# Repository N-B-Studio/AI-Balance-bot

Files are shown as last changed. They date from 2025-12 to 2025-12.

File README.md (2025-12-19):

# FOC-STM32-Balance-bot
FOC balance bot based on odrive-mini, STM32 and Linux PC
### Build video: https://youtu.be/XxXtfrMc1Zo
cover

## Project Overview
This project implements a self-balancing robot with AI capabilities, combining embedded STM32H7 firmware with Linux-based control scripts and face detection capabilities.

## Directory Structure & File Functions

### `/linux/` - Linux PC Control Scripts
Control scripts for the Raspberry Pi that interface with the STM32 microcontroller:

- **`h725_rc_joystick.py`** - Basic gamepad control script
  - Reads gamepad input from `/dev/input/event2`
  - Maps joystick axes to RC control values (-100 to 100)
  - Sends UART frames to STM32H725 via `/dev/serial0` (115200 baud)
  - Frame format: `0xAA 0x55 [FB] [LR] [checksum]` for forward/back and left/right control

- **`h725_rc_joystick_face.py`** - Gamepad control with face detection integration
  - Extends `h725_rc_joystick.py` with camera-based face detection
  - Uses Picamera2 to capture video frames (640x480)
  - Integrates with `face_detect.py` to detect faces using Haar Cascade classifier
  - Enables face-yaw mode when TL button is held (controls yaw based on face position)
  - Combines gamepad input with AI-based visual feedback

- **`face_detect.py`** - Face detection module
  - Uses OpenCV Haar Cascade classifier for real-time face detection
  - Captures frames from Raspberry Pi camera via Picamera2
  - Rotates frames 90° counterclockwise for proper orientation
  - Detects faces with configurable parameters (scaleFactor=1.3, minNeighbors=5, minSize=60x60)
  - Outputs detected face count and coordinates

- **`read_gamepad.py`** - Simple gamepad input reader
  - Basic utility to test gamepad connectivity
  - Reads raw controller events and displays them to console
  - Useful for debugging input device configuration

- **`read_elrs_crsf.py`** - ELRS/CRSF protocol decoder
  - Decodes ELRS (ExpressLRS) RC control signals via CRSF protocol
  - Runs at 420000 baud on `/dev/serial0`
  - Decodes RC_CHANNELS_PACKED frames (16 channels, 11-bit resolution: 0-2047)
  - Provides alternative to gamepad input using RC transmitter

- **`take_photo.py`** - Camera utility script
  - Captures still images from Raspberry Pi camera (640x480 resolution)
  - Saves photos in raw format and rotated versions (90° CW/CCW)
  - Useful for camera calibration and testing

### `/STM32/` - STM32H723 Embedded Firmware
Main firmware for the balance control MCU:

- **`Core/Inc/`** - Header files
  - `main.h` - Main program definitions
  - `BMI088*.h` - 6-axis IMU (accelerometer + gyroscope) driver headers
  - `bsp_fdcan.h`, `fdcan.h` - FDCAN/CAN communication interface
  - `usart.h`, `spi.h`, `dma.h` - Peripheral communication drivers
  - `gpio.h`, `tim.h` - GPIO and timer configurations

- **`Core/Src/`** - Source implementation files
  - `main.c` - Main control loop
  - `BMI088driver.c` - Low-level IMU register read/write
  - `BMI088Middleware.c` - High-level IMU data processing
  - `bsp_fdcan.c` - CAN bus initialization and handling
  - `usart.c`, `spi.c` - Serial and SPI communication
  - Other support files for system initialization

- **`Drivers/`** - STM32 HAL libraries and CMSIS
  - Hardware Abstraction Layer (HAL) for STM32H7xx
  - CMSIS (Cortex Microcontroller Software Interface Standard) headers

### `/3D-Model/` - CAD Files
3D CAD models for the robot mechanical structure and parts

### `/LICENSE` and `/README.md`
Project licensing information and this documentation file

## Hardware Components
- **MCU**: STM32H723 (ARM Cortex-M7)
- **IMU**: BMI088 (6-axis: 3-axis accelerometer + 3-axis gyroscope)
- **Motor Driver**: ODrive Mini (FOC - Field Oriented Control)
- **Controller**: Raspberry Pi or similar Linux board
- **Camera**: Raspberry Pi Camera Module 2
- **Communication**: UART (serial) for command interface, FDCAN for advanced control

## Communication Protocol
The main control protocol between Linux and STM32 is:
```
Frame: [0xAA] [0x55] [Forward/Back] [Left/Right] [Checksum]
- Forward/Back: -100 to 100 (signed 8-bit)
- Left/Right: -100 to 100 (signed 8-bit)
- Checksum: Sum of all bytes modulo 256
Baud Rate: 115200
```

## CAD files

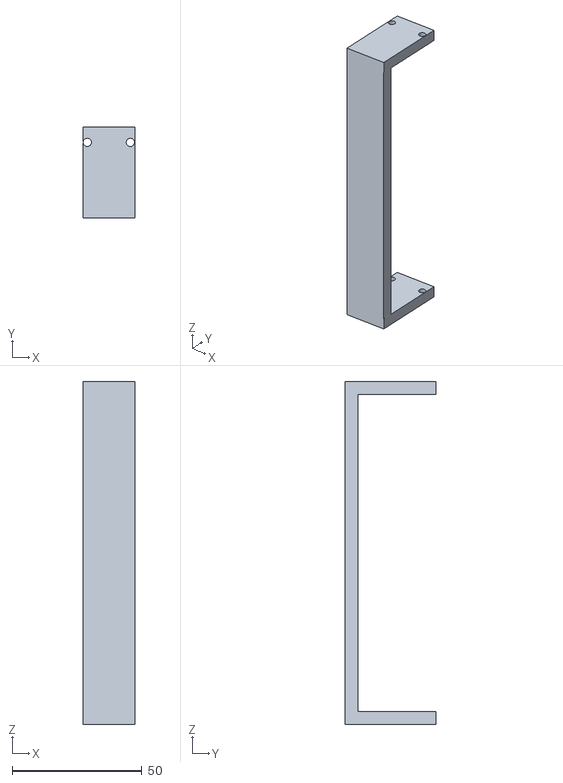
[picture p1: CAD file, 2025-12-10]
3D-Model/top.stl
20.0 x 35.0 x 132.0

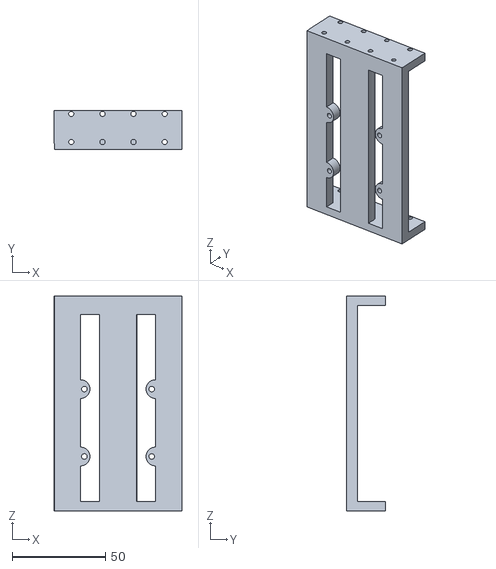
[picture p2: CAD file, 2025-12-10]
3D-Model/base.stl
68.3 x 21.0 x 115.0

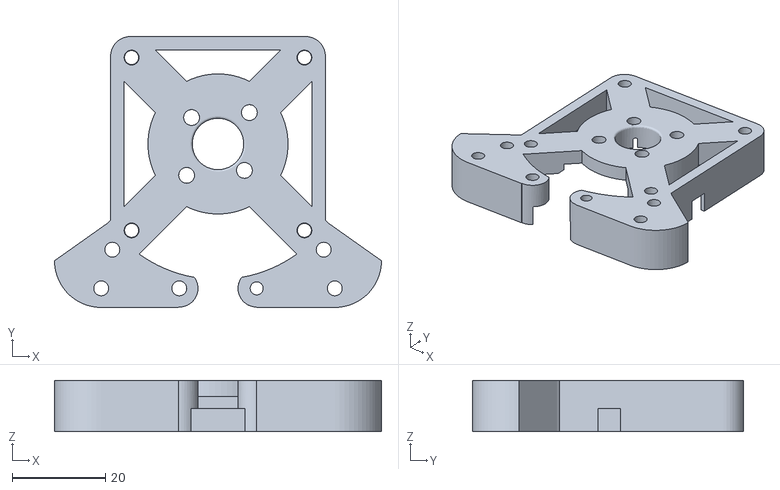
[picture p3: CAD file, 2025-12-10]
3D-Model/motor-base.stl
70.0 x 58.0 x 11.0

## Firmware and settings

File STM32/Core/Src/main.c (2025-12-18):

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
/* Includes ------------------------------------------------------------------*/
#include "main.h"
#include "dma.h"
#include "fdcan.h"
#include "spi.h"
#include "tim.h"
#include "usart.h"
#include "gpio.h"

/* USER CODE BEGIN Includes */
//#include "BMI088driver.h"
#include "BMI088Middleware.h"
#include <string.h>
#include <stdio.h>
/* USER CODE END Includes */


/* USER CODE BEGIN PV */
// --- Speed control loop configuration ---
    float v_target = 0.0f;          // Target linear velocity (can be 0 initially; later from RC/manual)
    float Kv_p     = 0.1f;          // Velocity P gain (tune gradually)
    float Kv_i     = 0.01f;         // Velocity I gain (start small)

    float v_integral      = 0.0f;
    float v_integral_limit = 5.0f;  // Prevent integral windup

    float base_pitch       = -1.5f; // Calibrated base pitch (degrees)
    float pitch_speed_limit = 6.0f; // Maximum pitch offset from joystick (degrees)
    float torque_limit      = 1.5f; // Max motor torque headroom


    // Velocity loop frequency: 1kHz / 10 = 100 Hz
	#define VEL_LOOP_DIV 10
	uint8_t vel_loop_counter = 0;

	volatile float odrive_left_vel  = 0.0f;
	volatile float odrive_right_vel = 0.0f;
	volatile float odrive_left_pos  = 0.0f;
	volatile float odrive_right_pos = 0.0f;

    // ===== YAW control =====
    float yaw               = 0.0f;      // Current yaw angle (approx. from integration)
    float Ky_p              = 0.0f;      // Yaw angle P gain
    float Ky_d              = 0.02f;     // Yaw rate D gain
    float yaw_torque_limit  = 0.4f;      // Maximum torque allocated to yaw

    // Wheel / robot geometry parameters (adjust to your robot)
    #define WHEEL_RADIUS_M   0.06f   // 0.06 m (example: 6 cm radius)
    #define GEAR_RATIO       1.0f    // Use 1.0 for direct drive, or set gearbox reduction ratio

    // Position loop
    float x_target      = 0.0f;     // Desired robot position (x=0)
    float Kx_p          = 0.0f;     // Position P gain (try 0.5~2 to start)
    float Kx_i          = 0.0f;     // Position I (start disabled; enable after tuning)
    float x_integral    = 0.0f;
    float x_int_limit   = 0.5f;     // Integral limit (meters)

    // Record initial average position at power-up
    float x0_turns = 0.0f;          // Origin in wheel turns
    uint8_t pos_initialized = 0;    // Position initialization flag

    // Global variables:
	volatile float odrive_left_pos_turns  = 0.0f;
	volatile float odrive_right_pos_turns = 0.0f;
	volatile float odrive_left_vel_turns  = 0.0f;
	volatile float odrive_right_vel_turns = 0.0f;

	// === RC command from Pi (forward/back & left/right) ===
	volatile float rc_fb = 0.0f;   // -1.0 .. +1.0 (forward/back)
	volatile float rc_lr = 0.0f;   // -1.0 .. +1.0 (left/right turn)

	static uint8_t uart10_rx_byte = 0;

	// UART10 simple frame parser state
	typedef enum {
	    RC_STATE_WAIT_AA = 0,
	    RC_STATE_WAIT_55,
	    RC_STATE_FB,
	    RC_STATE_LR,
	    RC_STATE_CHK
	} RC_State_t;

	static RC_State_t rc_state = RC_STATE_WAIT_AA;
	static int8_t rc_fb_int = 0;
	static int8_t rc_lr_int = 0;
	static uint8_t rc_checksum = 0;
	static uint8_t rc_sum = 0;
	// debug:
	volatile uint32_t rc_byte_count      = 0;   // total bytes seen on USART1
	volatile uint32_t rc_frame_ok_count  = 0;   // frames with correct checksum
	volatile int8_t   rc_last_fb_int     = 0;
	volatile int8_t   rc_last_lr_int     = 0;

	volatile uint8_t  rc_last_byte       = 0;

/* USER CODE END PV */

void SystemClock_Config(void);
/* USER CODE BEGIN 0 */
#include "bsp_fdcan.h"

// ===== Debug: loop frequency & UART print =====
char uart_buf[128];
uint32_t loop_counter  = 0;
uint32_t last_print_ms = 0;

// ===== Mini ODrive CAN constants =====
#define ODRIVE_LEFT_NODE_ID   2   // CAN1
#define ODRIVE_RIGHT_NODE_ID  3   // CAN2

#define CMD_SET_AXIS_STATE       0x07
#define CMD_SET_CONTROLLER_MODE  0x0B
#define CMD_SET_INPUT_TORQUE     0x0E
#define CMD_GET_ENCODER_ESTIMATES  0x09

#define AXIS_STATE_IDLE          1
#define AXIS_STATE_CLOSED_LOOP   8

#define CONTROL_MODE_TORQUE      1
#define INPUT_MODE_PASSTHROUGH   1

// 1 kHz loop
volatile uint8_t imu_loop_flag = 0;
volatile float   pitch = 0.0f;
volatile float   roll  = 0.0f;

#define RAD2DEG 57.2957795f
const float dt = 0.001f;    // 1 kHz

// ===== Balance controller gains (tune these) =====
float Kp = 0.004f;            // proportional on angle (deg)
float Kd = 0.02f;           // derivative on rate (deg/s)
float Ki = 0.008f;            // you can start with 0

float pitch_target = 0.0f;
float integral_term = 0.0f;
float integral_limit = 10.0f;

// ===== CAN helper =====
static inline uint16_t odrive_build_id(uint8_t node_id, uint8_t cmd_id)
{
    return ((uint16_t)node_id << 5) | (cmd_id & 0x1F);
}

void odrive_set_axis_state(FDCAN_HandleTypeDef *hcan, uint8_t node_id, uint32_t state)
{
    uint8_t data[8] = {0};
    data[0] = (uint8_t)(state & 0xFF);
    data[1] = (uint8_t)((state >> 8) & 0xFF);
    data[2] = (uint8_t)((state >> 16) & 0xFF);
    data[3] = (uint8_t)((state >> 24) & 0xFF);

    uint16_t id = odrive_build_id(node_id, CMD_SET_AXIS_STATE);
    fdcanx_send_data(hcan, id, data, 4);
}

void odrive_set_controller_mode(FDCAN_HandleTypeDef *hcan,
                                uint8_t node_id,
                                uint32_t control_mode,
                                uint32_t input_mode)
{
    uint8_t data[8];

    data[0] = (uint8_t)(control_mode & 0xFF);
    data[1] = (uint8_t)((control_mode >> 8) & 0xFF);
    data[2] = (uint8_t)((control_mode >> 16) & 0xFF);
    data[3] = (uint8_t)((control_mode >> 24) & 0xFF);

    data[4] = (uint8_t)(input_mode & 0xFF);
    data[5] = (uint8_t)((input_mode >> 8) & 0xFF);
    data[6] = (uint8_t)((input_mode >> 16) & 0xFF);
    data[7] = (uint8_t)((input_mode >> 24) & 0xFF);

    uint16_t id = odrive_build_id(node_id, CMD_SET_CONTROLLER_MODE);
    fdcanx_send_data(hcan, id, data, 8);
}

void odrive_set_input_torque(FDCAN_HandleTypeDef *hcan, uint8_t node_id, float torque)
{
    uint8_t data[8] = {0};

    union {
        float f;
        uint8_t b[4];
    } u;
    u.f = torque;

    data[0] = u.b[0];
    data[1] = u.b[1];
    data[2] = u.b[2];
    data[3] = u.b[3];

    uint16_t id = odrive_build_id(node_id, CMD_SET_INPUT_TORQUE);
    fdcanx_send_data(hcan, id, data, 4);
}


    typedef struct {
        float pos_turns;   // Position in wheel turns
        float vel_turns_s; // Velocity in turns per second
    } OdriveState;

OdriveState odrive_get_state(FDCAN_HandleTypeDef *hcan, uint8_t node_id)
{
    OdriveState st = {0.0f, 0.0f};

    uint16_t req_id = odrive_build_id(node_id, CMD_GET_ENCODER_ESTIMATES);

    uint8_t tx_data[8] = {0};
    fdcanx_send_data(hcan, req_id, tx_data, 0);  // Request

    uint32_t start = HAL_GetTick();
    uint16_t rec_id;
    uint8_t rx_buf[8];

    while ((HAL_GetTick() - start) < 2)   // Wait at most 2 ms
    {
        uint8_t len = fdcanx_receive(hcan, &rec_id, rx_buf);
        if (len > 0 && rec_id == req_id)
        {
            union { float f; uint8_t b[4]; } u_pos, u_vel;
            u_pos.b[0] = rx_buf[0];
            u_pos.b[1] = rx_buf[1];
            u_pos.b[2] = rx_buf[2];
            u_pos.b[3] = rx_buf[3];

            u_vel.b[0] = rx_buf[4];
            u_vel.b[1] = rx_buf[5];
            u_vel.b[2] = rx_buf[6];
            u_vel.b[3] = rx_buf[7];

            st.pos_turns   = u_pos.f;
            st.vel_turns_s = u_vel.f;
            return st;
        }
    }

    return st; // Return zeros if no response received
}

// === RC UART frame parser: 0xAA 0x55 fb_int lr_int checksum ===
static void RC_UART_ProcessByte(uint8_t b)
{
    switch (rc_state)
    {
    case RC_STATE_WAIT_AA:
        if (b == 0xAA) {
            rc_state = RC_STATE_WAIT_55;
            rc_sum = b;
        }
        break;

    case RC_STATE_WAIT_55:
        if (b == 0x55) {
            rc_state = RC_STATE_FB;
            rc_sum += b;
        } else {
            rc_state = RC_STATE_WAIT_AA;
        }
        break;

    case RC_STATE_FB:
        rc_fb_int = (int8_t)b;
        rc_sum += b;
        rc_state = RC_STATE_LR;
        break;

    case RC_STATE_LR:
        rc_lr_int = (int8_t)b;
        rc_sum += b;
        rc_state = RC_STATE_CHK;
        break;

    case RC_STATE_CHK:
        rc_checksum = b;
        if ((rc_sum & 0xFF) == rc_checksum)
        {
            rc_fb = (float)rc_fb_int / 100.0f;
            rc_lr = (float)rc_lr_int / 100.0f;

            rc_frame_ok_count++;
            rc_last_fb_int = rc_fb_int;
            rc_last_lr_int = rc_lr_int;
        }
        rc_state = RC_STATE_WAIT_AA;
        break;

    default:
        rc_state = RC_STATE_WAIT_AA;
        break;
    }
}
/* USER CODE END 0 */

/**
  * @brief  The application entry point.
  * @retval int
  */
int main(void)
{

  /* MCU Configuration--------------------------------------------------------*/

  /* Reset of all peripherals, Initializes the Flash interface and the Systick. */
  HAL_Init();

  /* Configure the system clock */
  SystemClock_Config();

  /* Initialize all configured peripherals */
  MX_GPIO_Init();
  MX_DMA_Init();
  MX_SPI2_Init();
  MX_USART1_UART_Init();
  MX_TIM2_Init();
  MX_FDCAN1_Init();
  MX_FDCAN2_Init();
  MX_USART10_UART_Init();
  /* USER CODE BEGIN 2 */

  // Start UART10 RX interrupt for RC frames from Pi
  HAL_UART_Receive_IT(&huart10, &uart10_rx_byte, 1);
  // GPIO, FDCAN, USART, TIM, SPI already in MX_*_Init();

    // Enable motor power (adjust pins if needed)
    HAL_GPIO_WritePin(GPIOC, GPIO_PIN_14, GPIO_PIN_SET);
    HAL_GPIO_WritePin(GPIOC, GPIO_PIN_13, GPIO_PIN_SET);
    HAL_GPIO_WritePin(GPIOC, GPIO_PIN_15, GPIO_PIN_SET);
    HAL_Delay(20);

    // Init CANs (this calls HAL_FDCAN_Start etc.)
    bsp_can_init();
    HAL_Delay(200);

    // Init IMU
    uint8_t imu_err = BMI088_init();
    // (optional) print ok/err via UART here

    // Start TIM2 1kHz interrupt
    HAL_TIM_Base_Start_IT(&htim2);

    // Put both ODrives into CLOSED_LOOP torque mode
    odrive_set_axis_state(&hfdcan1, ODRIVE_LEFT_NODE_ID,  AXIS_STATE_CLOSED_LOOP);
    HAL_Delay(100);
    odrive_set_controller_mode(&hfdcan1, ODRIVE_LEFT_NODE_ID, CONTROL_MODE_TORQUE, INPUT_MODE_PASSTHROUGH);
    HAL_Delay(100);

    odrive_set_axis_state(&hfdcan2, ODRIVE_RIGHT_NODE_ID, AXIS_STATE_CLOSED_LOOP);
    HAL_Delay(100);
    odrive_set_controller_mode(&hfdcan2, ODRIVE_RIGHT_NODE_ID, CONTROL_MODE_TORQUE, INPUT_MODE_PASSTHROUGH);
    HAL_Delay(100);

  /* USER CODE END 2 */

  /* Infinite loop */
  /* USER CODE BEGIN WHILE */
    float gyro[3];
    float accel[3];
    float temp = 0.0f;

    float prev_error = 0.0f;

    // === Init debug timing ===
    last_print_ms = HAL_GetTick();
    // add this:
    pitch_target = base_pitch;
  while (1)
  {
	  if (!imu_loop_flag)
	           continue;
	       imu_loop_flag = 0;

	       // 1) Read IMU
	       BMI088_read(gyro, accel, &temp);

	       // 2) Complementary filter to update pitch / roll
	       // (reuse your old code; sketch shown here)

	       const float alpha = 0.98f;
	       float ax = accel[0];
	       float ay = accel[1];
	       float az = accel[2];
	       float gx = gyro[0];   // deg/s
	       float gy = gyro[1];   // deg/s
	       float gz = gyro[2];   // deg/s  <-- YAW

	       float pitch_acc = atan2f(-ax, sqrtf(ay * ay + az * az)) * RAD2DEG;
	       float roll_acc  = atan2f( ay, az ) * RAD2DEG;

	       // assuming gy is pitch rate
	       pitch = alpha * (pitch + gy * dt) + (1.0f - alpha) * pitch_acc;
	       roll  = alpha * (roll  + gx * dt) + (1.0f - alpha) * roll_acc;
        yaw += gz * dt;   // Yaw in degrees; approximate heading (will drift over time)

	       // ==================== vel + pos loop ===========================
	       vel_loop_counter++;
	       if (vel_loop_counter >= VEL_LOOP_DIV)
	       {
	           vel_loop_counter = 0;

               // 1) Read ODrive state (kept for future position/velocity usage)
	           OdriveState st_left  = odrive_get_state(&hfdcan1, ODRIVE_LEFT_NODE_ID);
	           OdriveState st_right = odrive_get_state(&hfdcan2, ODRIVE_RIGHT_NODE_ID);

	           odrive_left_pos_turns  = st_left.pos_turns;
	           odrive_right_pos_turns = st_right.pos_turns;
	           odrive_left_vel_turns  = st_left.vel_turns_s;
	           odrive_right_vel_turns = st_right.vel_turns_s;

	           if (!pos_initialized)
	           {
	               x0_turns = 0.5f * (odrive_left_pos_turns + odrive_right_pos_turns);
	               pos_initialized = 1;
	           }

               // === RC forward/back: map directly to pitch offset ===
               float pitch_offset = rc_fb * pitch_speed_limit;   // rc_fb in [-1, 1]

	           pitch_target = base_pitch - pitch_offset;
	       }



        // =================== Attitude (pitch) PID =======================
        float error = pitch_target - pitch;     // target = 0 deg

	       integral_term += error * dt;
	       if (integral_term >  integral_limit) integral_term =  integral_limit;
	       if (integral_term < -integral_limit) integral_term = -integral_limit;

        float derivative = -gy;   // gy>0 forward tilt; derivative negative to provide damping/braking

	       float torque_cmd = Kp * error + Kd * derivative + Ki * integral_term;

        // Clamp torque command
	       if (torque_cmd >  torque_limit) torque_cmd =  torque_limit;
	       if (torque_cmd < -torque_limit) torque_cmd = -torque_limit;


        // =================== YAW PID (differential torque) =======================
	       // rc_lr ∈ [-1, +1]  →   yaw_torque ∈ [-yaw_torque_limit, +yaw_torque_limit]

        float yaw_torque = rc_lr * 0.1 * yaw_torque_limit;  // Primary control: RC (remote controller)

        // Optional: use gyro for damping to prevent divergence (acts like D term)
        float yaw_damping = Ky_d * gz;   // gz > 0 when turning; produces counter torque
	       yaw_torque -= yaw_damping;

        // Clamp yaw torque
	       if (yaw_torque >  yaw_torque_limit) yaw_torque =  yaw_torque_limit;
	       if (yaw_torque < -yaw_torque_limit) yaw_torque = -yaw_torque_limit;

        // =================== Compose left/right wheel torques =======================
        // Pitch contributes common-mode torque; yaw contributes differential torque
	       float left_torque  = torque_cmd + yaw_torque;
	       float right_torque = torque_cmd - yaw_torque;

        // (If yaw direction is reversed, swap the signs on left/right torques)

	       odrive_set_input_torque(&hfdcan1, ODRIVE_LEFT_NODE_ID,  -left_torque);
	       odrive_set_input_torque(&hfdcan2, ODRIVE_RIGHT_NODE_ID, right_torque);

	       prev_error = error;

	       // ===== DEBUG: measure loop frequency & print pitch =====
			 loop_counter++;
			 uint32_t now = HAL_GetTick();   // ms since boot

			 // print every 100 ms (10 Hz) so UART doesn't destroy timing
			 if ((now - last_print_ms) >= 100)
			 {
				 float elapsed_ms = (float)(now - last_print_ms);
				 float loop_hz    = (loop_counter * 1000.0f) / elapsed_ms;

				 int n = snprintf(uart_buf, sizeof(uart_buf),
				                  "[H725] pitch=%.2f pt=%.2f fb=%.2f lr=%.2f fb_int=%d frames=%lu loop=%.1fHz\r\n",
				                  pitch, pitch_target, rc_fb, rc_lr,
				                  (int)rc_fb_int,
				                  rc_frame_ok_count,
				                  loop_hz);

				 HAL_UART_Transmit(&huart1, (uint8_t*)uart_buf, n, 10);

				 loop_counter  = 0;
				 last_print_ms = now;
			 }

    /* USER CODE END WHILE */

    /* USER CODE BEGIN 3 */
  }
  /* USER CODE END 3 */
}

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
/* USER CODE BEGIN 4 */
void HAL_TIM_PeriodElapsedCallback(TIM_HandleTypeDef *htim)
{
    if (htim->Instance == TIM2)
    {
        imu_loop_flag = 1;
    }
}

void HAL_UART_RxCpltCallback(UART_HandleTypeDef *huart)
{
    if (huart->Instance == USART10)
    {
        rc_byte_count++;
        rc_last_byte = uart10_rx_byte;

        RC_UART_ProcessByte(uart10_rx_byte);

        // re-arm RX on UART10 (IMPORTANT: huart10, NOT huart1)
        HAL_UART_Receive_IT(&huart10, &uart10_rx_byte, 1);
    }
}


/* USER CODE END 4 */
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


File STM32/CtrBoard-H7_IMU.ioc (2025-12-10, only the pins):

Mcu.UserName=STM32H723VGTx
PA10.Signal=USART1_RX
PA13(JTMS/SWDIO).Signal=DEBUG_JTMS-SWDIO
PA14(JTCK/SWCLK).Signal=DEBUG_JTCK-SWCLK
PA9.Signal=USART1_TX
PB13.Signal=SPI2_SCK
PB5.Signal=FDCAN2_RX
PB6.Signal=FDCAN2_TX
PC0.GPIO_Label=ACC_CS
PC0.Signal=GPIO_Output
PC1.Signal=SPI2_MOSI
PC13.Signal=GPIO_Output
PC14-OSC32_IN.Signal=GPIO_Output
PC15-OSC32_OUT.Signal=GPIO_Output
PC2_C.Signal=SPI2_MISO
PC3_C.GPIO_Label=GYRO_CS
PC3_C.Signal=GPIO_Output
PD0.Signal=FDCAN1_RX
PD1.Signal=FDCAN1_TX
PE10.GPIO_Label=ACC_INT
PE10.Signal=GPXTI10
PE12.GPIO_Label=GYRO_INT
PE12.Signal=GPXTI12
PE2.Signal=USART10_RX
PE3.Signal=USART10_TX
PH0-OSC_IN.Signal=RCC_OSC_IN
PH1-OSC_OUT.Signal=RCC_OSC_OUT

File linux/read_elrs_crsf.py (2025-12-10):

#!/usr/bin/env python3
import serial

PORT = "/dev/serial0"   # UART on GPIO14/15
BAUD = 420000           # CRSF default

CRSF_ADDR_MODULE = 0xC8
CRSF_TYPE_RC_CHANNELS_PACKED = 0x16

def decode_crsf_rc_channels(payload: bytes):
    """
    Decode CRSF RC_CHANNELS_PACKED payload (expected 22 bytes)
    into 16 x 11-bit values (0..2047).
    Returns list of 16 ints.
    """
    if len(payload) < 22:
        return None

    channels = []
    bitbuf = 0
    bits_in_buf = 0

    for b in payload[:22]:
        bitbuf |= b << bits_in_buf
        bits_in_buf += 8

        while bits_in_buf >= 11 and len(channels) < 16:
            ch = bitbuf & 0x7FF  # 11 bits
            channels.append(ch)
            bitbuf >>= 11
            bits_in_buf -= 11

    return channels[:16]

def crsf_to_norm(ch_val: int) -> float:
    """
    Very simple normalization:
    CRSF raw ~ 172..1811, mid ~ 992.
    Map roughly to -1.0 .. +1.0.
    """
    # keep it simple and robust:
    return max(-1.0, min(1.0, (ch_val - 992) / 820.0))

def main():
    print(f"Opening {PORT} @ {BAUD} baud for CRSF...")
    ser = serial.Serial(
        PORT,
        BAUD,
        bytesize=serial.EIGHTBITS,
        parity=serial.PARITY_NONE,
        stopbits=serial.STOPBITS_ONE,
        timeout=0.1,
    )

    state = 0
    frame_len = 0
    frame_data = bytearray()

    while True:
        b = ser.read(1)
        if not b:
            continue
        byte = b[0]

        if state == 0:
            # look for CRSF address
            if byte == CRSF_ADDR_MODULE:
                state = 1
        elif state == 1:
            frame_len = byte
            frame_data = bytearray()
            state = 2
        elif state == 2:
            frame_data.append(byte)
            if len(frame_data) >= frame_len:
                # we have full frame: [type][payload...][crc]
                frame_type = frame_data[0]
                payload = frame_data[1:-1]  # ignore CRC for now

                if frame_type == CRSF_TYPE_RC_CHANNELS_PACKED:
                    channels = decode_crsf_rc_channels(payload)
                    if channels:
                        ch8 = channels[:8]

                        # pretty print raw + normalized
                        raw_str = " ".join(f"{v:4d}" for v in ch8)
                        norm_str = " ".join(f"{crsf_to_norm(v):+0.2f}" for v in ch8)
                        print(f"RAW  CH1-8: {raw_str}   |   NORM: {norm_str}")

                # reset state to search next frame
                state = 0

if __name__ == "__main__":
    try:
        main()
    except KeyboardInterrupt:
        print("\nExiting.")

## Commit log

2025-12-10 add stm32
2025-12-10 add 3d model
    [base.stl, motor-base.stl, top.stl]

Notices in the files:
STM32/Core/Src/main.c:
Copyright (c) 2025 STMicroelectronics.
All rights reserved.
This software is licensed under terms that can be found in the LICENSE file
